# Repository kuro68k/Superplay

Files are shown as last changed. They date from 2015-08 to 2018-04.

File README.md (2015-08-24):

# SUPERPLAY

SUPERPLAY is an arcade joystick controller system. It consists of serveral parts.

The main SUPERPLAY PCB is fitted to the joystick and can either connect via USB or a custom KBUS. Both use the same USB cable. Configuration is via a Windows app called SPConfig.

SUPERPLAY supports up to 16 buttons, multiple autofire configurations with selectable fire rate, multiple options for switching modes and rotary joysticks (Seimitsu LS-30, used by SNK) for games like Midnight Resistance. Rotary joystick support is compatible with MAME, and configurable. SUPERPLAY also supports expansion boards via an expansion header, similar to Arduino sheilds.

####True zero lag

Many joystick controllers claim to be zero lag, but as FPS players know USB introduces some delay. USB HID devices are polled at 120Hz maximum, resulting in up to 8ms of lag (1/2 a frame at 60Hz). FPS players hack the Windows mouse driver to increase the poll rate, but it doesn't work for joysticks.

SUPERPLAY uses the excellent vJoy (vjoystick.sourceforge.net) and a custom USB interface to increase the polling rate to 1000Hz, reducing lag down to 1ms maximum. This gives true zero, arcade/console levels of input lag (i.e. none).

####Autofire

SUPERPLAY has a special autofire implementation that allows the player to set a precise frequency, and ensures that a button press is always registered when the button is first pushed. Simple autofire systems switch in a square wave, so the button press is sometimes not registered until the "on" part of the square wave comes around.

####KBUS

Aside from USB, SUPERPLAY can be connected to KBUS devices. Currently under development are a supergun with KBUS support, and a number of "recievers". Recievers connect to games consoles. The first is planned to support Playstation 1/2, Saturn and Dreamcast. Unfortunately due to licencing agreements Dreamcast support will not be published.

KBUS uses a simple 3.3V "RS232" compatible protocol, that can be easily implemented on low cost microcontrollers.

####Other stuff

A HID based USB bootloader will be provided for firmware and configuration updates. See my other projects for code.

The main SUPERPLAY PCB uses an XMEGA 128A3U microcontroller. This might be revised down to a 64KB in future. The project opens with Atmel Studio 6.2. Schematic and gerbers created in Eagle. V1.0 hardware has been built, V1.1 corrects a few issues.

SPConfig is built in Visual Studio 2013 Community Edition. I uses MahApps.Metro to create a "modern" UI.

Everything is licenced under GPL v3.

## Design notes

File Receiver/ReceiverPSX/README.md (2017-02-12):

# ReceiverPSX #

KBUS Receiever for:

- Sony Playstation 1
- Sony Playstation 2

Currently emulating a basic digital only pad.

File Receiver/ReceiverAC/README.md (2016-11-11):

# ReceiverACPS #

KBUS Receiever for:

- Atari/Commodore style 9 pin joystick ports  
  - Amiga (1-3 buttons)  
  - C64  
  - Atari 2600 / 7800 / ST etc.  
  - Many other 8/16 bit machines
- PC-Engine (Turbografx-16)
- Sega Master System
- Sega Megadrive (Genesis)

Any other simple switch/multiplex based system can also be supported, with the caveat that de-multiplexing is not as fast as real logic. Sega specify a 2uS delay from changing the multiplex selection to reading the outputs.

The generic XMEGA E5 receiver hardware is used. KBUS specifies 250mA @ 5V. Some systems, such as the Amiga, can't provide this from the joystick port so must get 5V from elsewhere (e.g. the floppy port). Of course not all KBUS devices need 250mA, so you may get away without it.

Lag is sub 1ms ("true zero", or at least 10x better than USB).

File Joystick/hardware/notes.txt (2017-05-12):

V1.0:	First issue

V1.1:	Minor fixes, firmware compatible.
		Fixed screw terminal hole sizes
		Moved test points further apart
		Added missing 1206 capacitor
		Revised logo

V1.2:	Connected PF4/UNUSED to LED
	Thickened lines in SUPERPLAY logos

V2 -> V1 mapping:

V2		V1
-------------
Up		Up
Down	Down
Left	Left
Right	Right

B1		B1
B2		B2
B3		B3
B4		B4
B5		B5
B6		B6
B7		B7
B8		B8
B9		Exp / AF low 1
B10		Exp / AF low 2
B11		Exp / AF low 3
B12		Exp / AF low 4
B13		AF low 6
B14		AF low 5
B15		Coin
B16		Start

A1		Unused
A2		Mode 4B
A3		Mode 4B AF
A4		Control
A5		AF high 1
A6		AF high 2
A7		AF high 3
A8		AF high 4

R1		R12
R2		R11
R3		R10
R4		R9
R5		R8
R6		R7
R7		R6
R8		R5
R9		R4
R10		R3
R11		R2
R12		R1

META	AF high 5
LED		AF high 6

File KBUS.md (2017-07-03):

# KBUS specification V0.1

KBUS is a high speed bus for video game controllers. It provides a low latency link and standard data format that is relatively easy to implement on common 8 bit microcontrollers and above. KBUS is a point-to-point bus, so there is always exactly one receiver and one device.

## Terminolgy

**Receiver**

The receiver is the bus master, issuing polling requests and other commands to devices. It's usually something like a PC or converter for a game console, which takes the player's input from devices.

**Device**

Devices respond to requests from the receiver by supplying data about user inputs. They are usually things like arcade joysticks, flight controls or converters for game console controllers. Devices are usually responsible for handling features like autofire, although receivers can optionally implement them as well.

## Electrical

KBUS uses RS232 signalling at 3.3V and 1M baud, 8 bits, no parity, 1 stop bit (8n1). This is easily implemented on most microcontrollers with a UART. Optionally, USB HID can be supported on the same cable with auto-detection.

Packets are separated by a gap of 2 or more characters.

The standard KBUS cable is a USB 2.0 cable. The type of connector on either end (A, B or C, micro, mini etc.) is not specified, but the standard full size A to B cable is cheap, readily available and fairly robust. D- is used for TX, and D+ for RX, from the receiver's point of view. Obviously, devices' TX/RX must be reversed.

`Receiver TX ---> USB D- ---> Device RX`
`Receiver RX <--- USB D+ <--- Device TX`

Power supplied to KBUS devices is 4.5-5.25V at 250mA. This allows for both standard USB 5V ±5% and for diode ORing of multiple supplies. Since signalling is at 3.3V it is expected that the supply voltage will be regulated down to that level anyway.

## Protocol

KBUS packets are 64 bytes long, for compatibility with USB HID. Each packet contains a command and up to 63 data bytes.

**KBUS over RS232 packet**

| Bytes | Description |
| :--- | :--- |
| 1 | Command code |
| 0-63 | Data |
| 2 | CCITT CRC-16 Checksum |

**KBUS over USB packet**

| Bytes | Description |
| :--- | :--- |
| 1 | Command code |
| 0-63 | Data |

USB handles the checksum as part of its own protocol, so there is no need to duplicate it. Commands are as follows:

| Command | Code | Description |
| :--- | :--- | :--- |
| ECHO | 0x50 | Echo data back, for testing/NOP |
| READ_STRING | 0x51 | Data byte indicates string ID<br>`0 - DEVICE_NAME`<br>`1 - MANUFACTURER`<br>`2 - SERIAL_NUMBER` |
| READ_VID_PID | 0x52 | Read 16 bit vendor/product IDs |
| | |
| START_REPORTING | 0x54 | Start sending continuous report packets at 1ms intervals |
| STOP_REPORTING | 0x55 | Stop sending continuous report packets |
| | |
| READ_REPORT | 0x5A | Request sending a report |
| | |
| ENTER_BOOTLOADER | 0x5B | Start bootloader (only on supported connections, e.g. USB) |

Strings are in Unicode UTF16-LE format, the same as USB. While Unicode has some severe limitations, USB compatibility makes it easy to implement dual protocol devices. To convert basic ISO 8859-1 / ASCII to UTF16-LE, just extend every byte to 16 bits and esure you have little-endian order. Strings do not need to be null terminated. Due to the packet length limit, the maximum string length is 31 characters.

Report packets must contain at least two data bytes, but can be up to 63 bytes. Currently only the following bytes are defined:

| Byte | Name | Description |
| :--- | :--- | :--- |
| 0 | UDLR_SSCC | (LSB) Up/down/left/right - start/select/coin/control (MSB) |
| 1 | BUTTONS1_8 | Buttons 1 - 8 (1 = LSB) |
| 2 | BUTTONS9_16 | Buttons 9 - 16 |
| 3 | ROT_MODE | Bits 0-3 - Rotary position 0-11<br>Bits 4-5 - Button mode<br>Bits 6-7 - Unused |

Receivers can ignore inputs they don't need / understand.

## Polling and activation

Receivers often need to poll KBUS ports to see if a device is attached. Polling also gives devices an opportunity to calibrate internal oscillators/UARTs and signal to the receiver that they are ready.

Polling starts by the receiver sending 64 0xFF bytes. 0xFF produces just one low pulse per byte that is 1uS wide. The receiver can measure the width of this bit for oscillator calibration / auto-bauding. When ready, the device should respond with 0x0F, which again provides useful timing data and an opportunity to test the receiver's UART. The device should keep transmitting until the receiver stops sending 0xFF bytes for at least 10ms. If the receiver does not see a response for 10ms, it can send another burst of 64 0xFF bytes and repeat the cycle indefinitely.

Once both receiver and device are quiet for at least 10ms, the receiver should send an ECHO command to test the link, followed optionally by polling IDs and strings, before starting to request reports.

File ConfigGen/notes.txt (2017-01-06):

Autofire affects _b inputs, not logical buttons. This allows physical buttons with and without AF for each logical button.

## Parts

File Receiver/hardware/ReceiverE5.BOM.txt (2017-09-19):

Title:      KBUS Receiver
Date:       12/07/2017 16:29:38
Source:     ReceiverE5.sch
Revsision:  2.1

No.  Reference             Value          Footprint                 Precision

[ Capacitors, 6 values, X7R/X5R, 16V unless otherwise stated ]
-----------------------------------------------------------------------------
2    C1, C2                22p            0603                      
1    C3                    4.7u           0603                      
6    C4, C5, C10, C11      100n           0603                      
     C12, C13
1    C6                    680p           0603                      
2    C7, C9                10u            0603                      
1    C8                    10u            0805                      

[ Diodes, 2 values ]
-----------------------------------------------------------------------------
1    D1                    LED            0603                      
1    D2                    MBR0520LT1G    SOD-123                   

[ Connectors, 5 values ]
-----------------------------------------------------------------------------
1    J1                    KBUS           Type A, TH, FCI 87520     
1    J2                    AVR-PDI-6A     Pin_Header_Straight_2x03  
1    J3                    CONN_01X08     no part                   
2    J4, J5                CONN_01X06     no part                   
2    J6, J7                CONN_01X04     no part                   

[ Inductors, 1 value ]
-----------------------------------------------------------------------------
1    L1                    6.8u           SRN4012TA                 

[ Resistors, 5 values, 1% unless otherwise stated ]
-----------------------------------------------------------------------------
3    R1, R2, R3            680            0603                      
1    R4                    47k            0603                      
1    R5                    15k            0603                      
1    R6                    2k2            0603                      
2    R7, R8                33             0603                      

[ SW, 1 value ]
-----------------------------------------------------------------------------
1    SW1                   SW_SPST        SW_SPST_EVQP7C            

[ Integrated Circuits, 5 values ]
-----------------------------------------------------------------------------
1    U1                    ATXMEGA32E5-A  TQFP-32                   
1    U2                    LM2731         SOT-23                    
2    U3, U4                SN74LV07A      SSOP-14                   
1    U5                    TPS78233       SOT-23                    
2    U6, U7                74LVC2T45      SOT-765-1                 

[ Crystals, 1 value ]
-----------------------------------------------------------------------------
1    Y1                    Crystal        QC6CB/7A/ABM7 crystals

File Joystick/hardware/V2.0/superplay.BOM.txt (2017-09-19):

Title:      SUPERPLAY joystick controller
Date:       12/07/2017 11:46:48
Source:     superplay.sch
Revsision:  2.0
Company:    KEIO

No.  Reference             Value            Footprint                       Precision

[ Capacitors, 5 values, X7R/X5R, 16V unless otherwise stated ]
-------------------------------------------------------------------------------------
1    C1                    1u               0603                            
1    C2                    100u             1206                            
1    C3                    10u              0603                            
6    C4, C5, C6, C7, C8    100n             0603                            
     C9
2    C10, C11              18p              0603                            

[ Diodes, 1 value ]
-------------------------------------------------------------------------------------
1    D1                    LED              0603                            

[ Connectors, 3 values ]
-------------------------------------------------------------------------------------
1    J1                    AVR-PDI-6A       3x2_1.27mm_SMD_header           
1    J2                    CONN_02X04       ...r_Straight_2x04_Pitch2.54mm  
1    J3                    USB_B            USB_Micro-B_Molex_47346-0001    

2    PA1, PA2              CONN_01X05       B5B-ZR-SM4-TF                   
4    PB1, PB2, PB3, PB4    CONN_01X05       B5B-ZR-SM4-TF                   
1    PJ1                   CONN_01X05       B5B-ZR-SM4-TF                   
1    PL1                   CONN_01X02       B2B-ZR-SM4-TF                   
1    PM1                   CONN_01X02       B2B-ZR-SM4-TF                   
3    PR1, PR2, PR3         CONN_01X05       B5B-ZR-SM4-TF                   

[ Resistors, 1 value, 1% unless otherwise stated ]
-------------------------------------------------------------------------------------
1    R1                    680R             0603                            

[ Integrated Circuits, 3 values ]
-------------------------------------------------------------------------------------
1    U1                    MCP1700T-3002E   SOT-23                          
1    U2                    ATXMEGA128A3U-A  TQFP-64_14x14mm_Pitch0.8mm      
1    U3                    TPD4S009DBV      SOT-23                          

[ Crystals, 1 value ]
-------------------------------------------------------------------------------------
1    Y1                    16MHz            QC6CB/7A/ABM7 crystals

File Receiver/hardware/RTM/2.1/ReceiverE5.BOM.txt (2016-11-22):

Title	KBUS Receiver
Date	22/11/2016 09:59:38
Source	ReceiverE5.sch
Revsision	2.0

Capacitors	6	X7R/X5R, 16V unless otherwise stated
	C1, C2	22p	0603	
	C6	680p	0603	
	C4, C5, C10, C11, C12, C13	100n	0603	
	C7, C9	10u	0603	
	C8	10u	0805	
	C3	4.7u	0603	

Diodes	2
	D2	MBR0520LT1G	SOD-123	
	D1	LED	0603	

Connectors	5
	J1	KBUS	Type A, TH, FCI 87520	
	J2	AVR-PDI-6A		

Inductors	1
	L1	6.8u		

Resistors	5	1% unless otherwise stated
	 R1, R2,R3	680	0603	
	R7, R8	33	0603	
	R6	2k2	0603	
	R5	15k	0603	
	R4	47k	0603	

Integrated Circuits	5
	U2	LM2731	SOT-23	
	U5	TPS78233	SOT-23	
	U1	ATXMEGA32E5-A	TQFP-32	
	U3, U4	SN74LV07A	SSOP-14	
	U6, U7	74LVC2T45	SOT-765-1	

Crystals	1
	Y1	Crystal	QC6CB/7A/ABM7 crystals

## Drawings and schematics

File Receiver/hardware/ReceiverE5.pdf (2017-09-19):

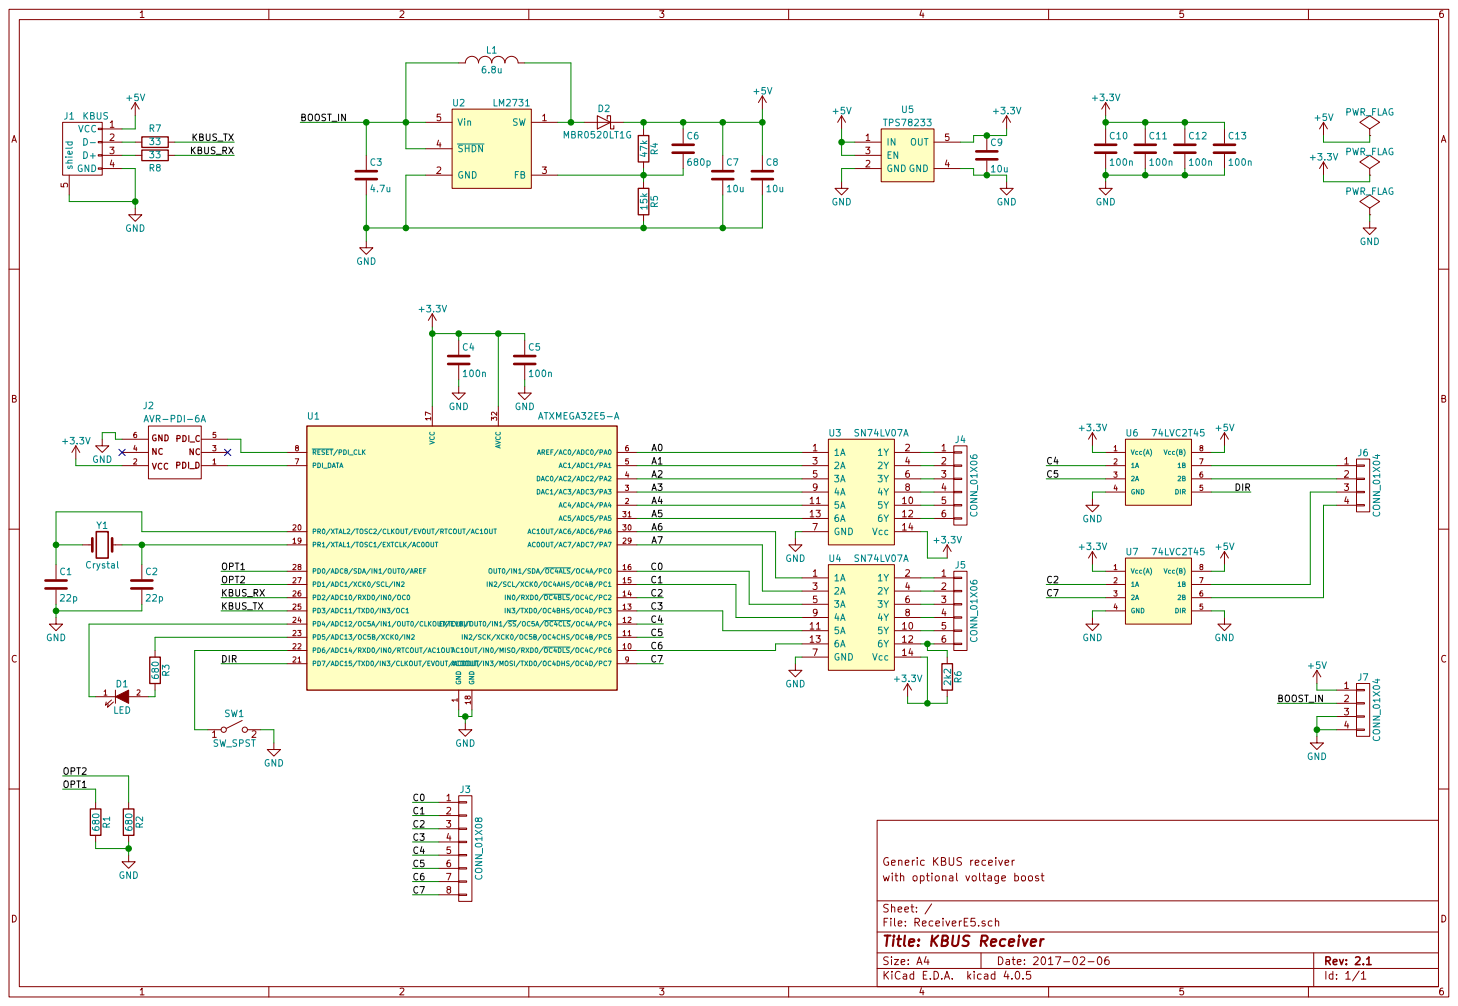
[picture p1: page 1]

1 AC4/ADC4/PA4 2 DAC1/AC3/ADC3/PA3 3 DAC0/AC2/ADC2/PA2 4 AC1/ADC1/PA1 5 AREF/AC0/ADC0/PA0 6 PDI_DATA 7 RESET/PDI_CLK 8 AC0OUT/IN3/MOSI/TXD0/OC4DHS/OC4D/PC7 9 AC1OUT/IN0/MISO/RXD0/OC4DLS/OC4C/PC6 10 PR0/XTAL2/TOSC2/CLKOUT/EVOUT/RTCOUT/AC1OUT 20 AC1OUT/AC6/ADC6/PA6 30

Id: 1/1 Title: KBUS Receiver File: ReceiverE5.sch Sheet: / with optional voltage boost Generic KBUS receiver

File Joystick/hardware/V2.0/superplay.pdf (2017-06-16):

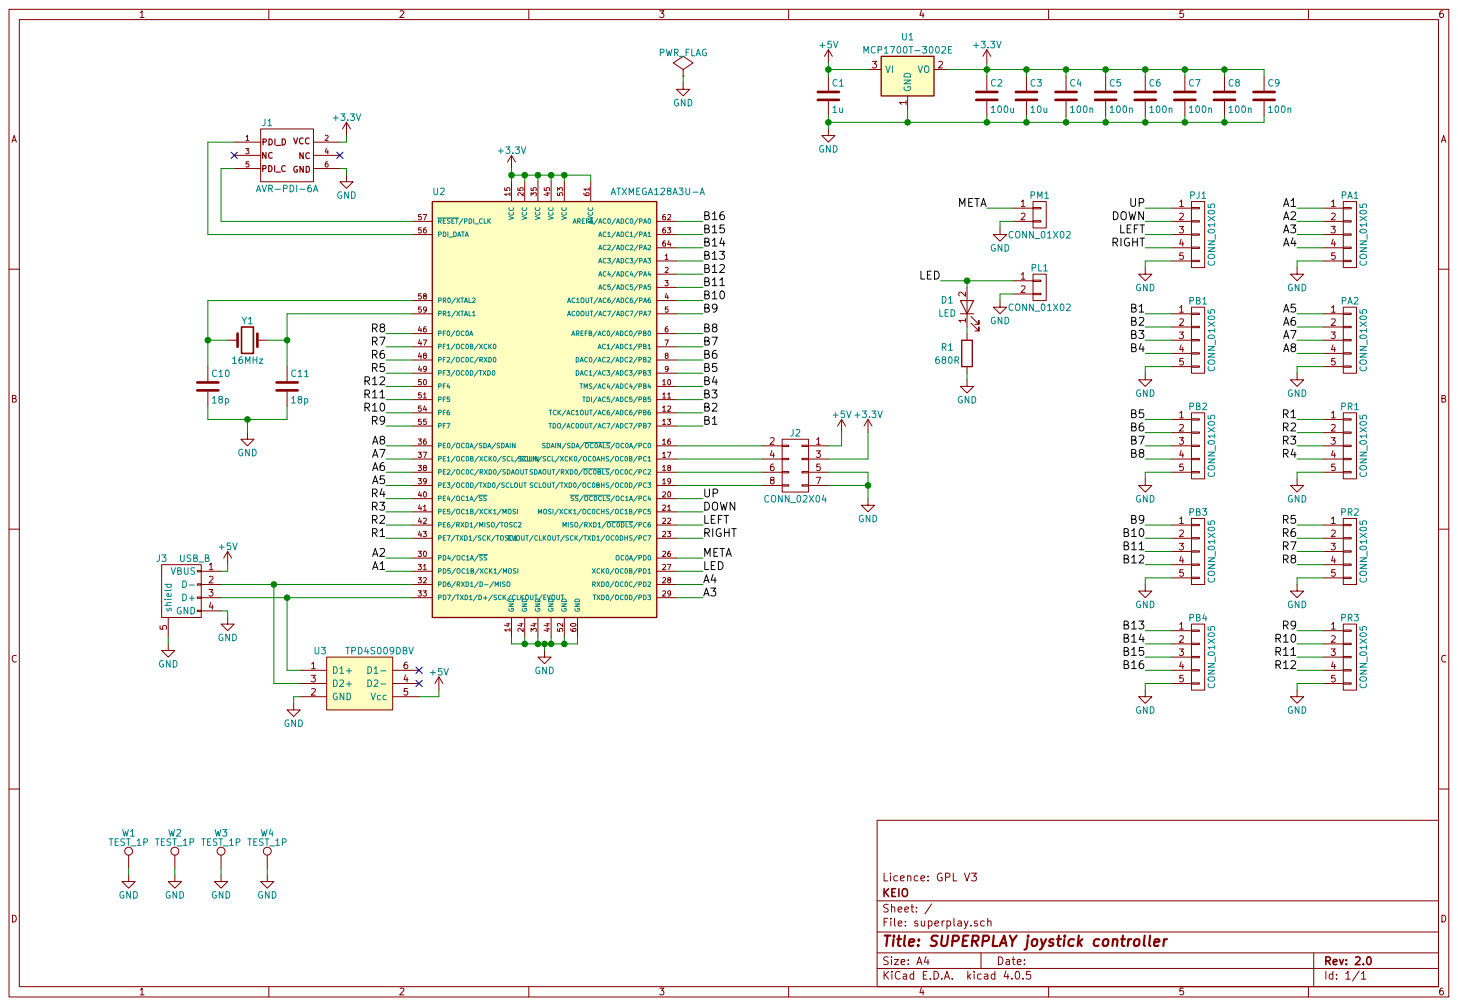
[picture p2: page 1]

2 PL1 CONN_01X02 GND GND GND META

Licence: GPL V3
File: superplay.sch Sheet: / KEIO

Id: 1/1 Title: SUPERPLAY joystick controller

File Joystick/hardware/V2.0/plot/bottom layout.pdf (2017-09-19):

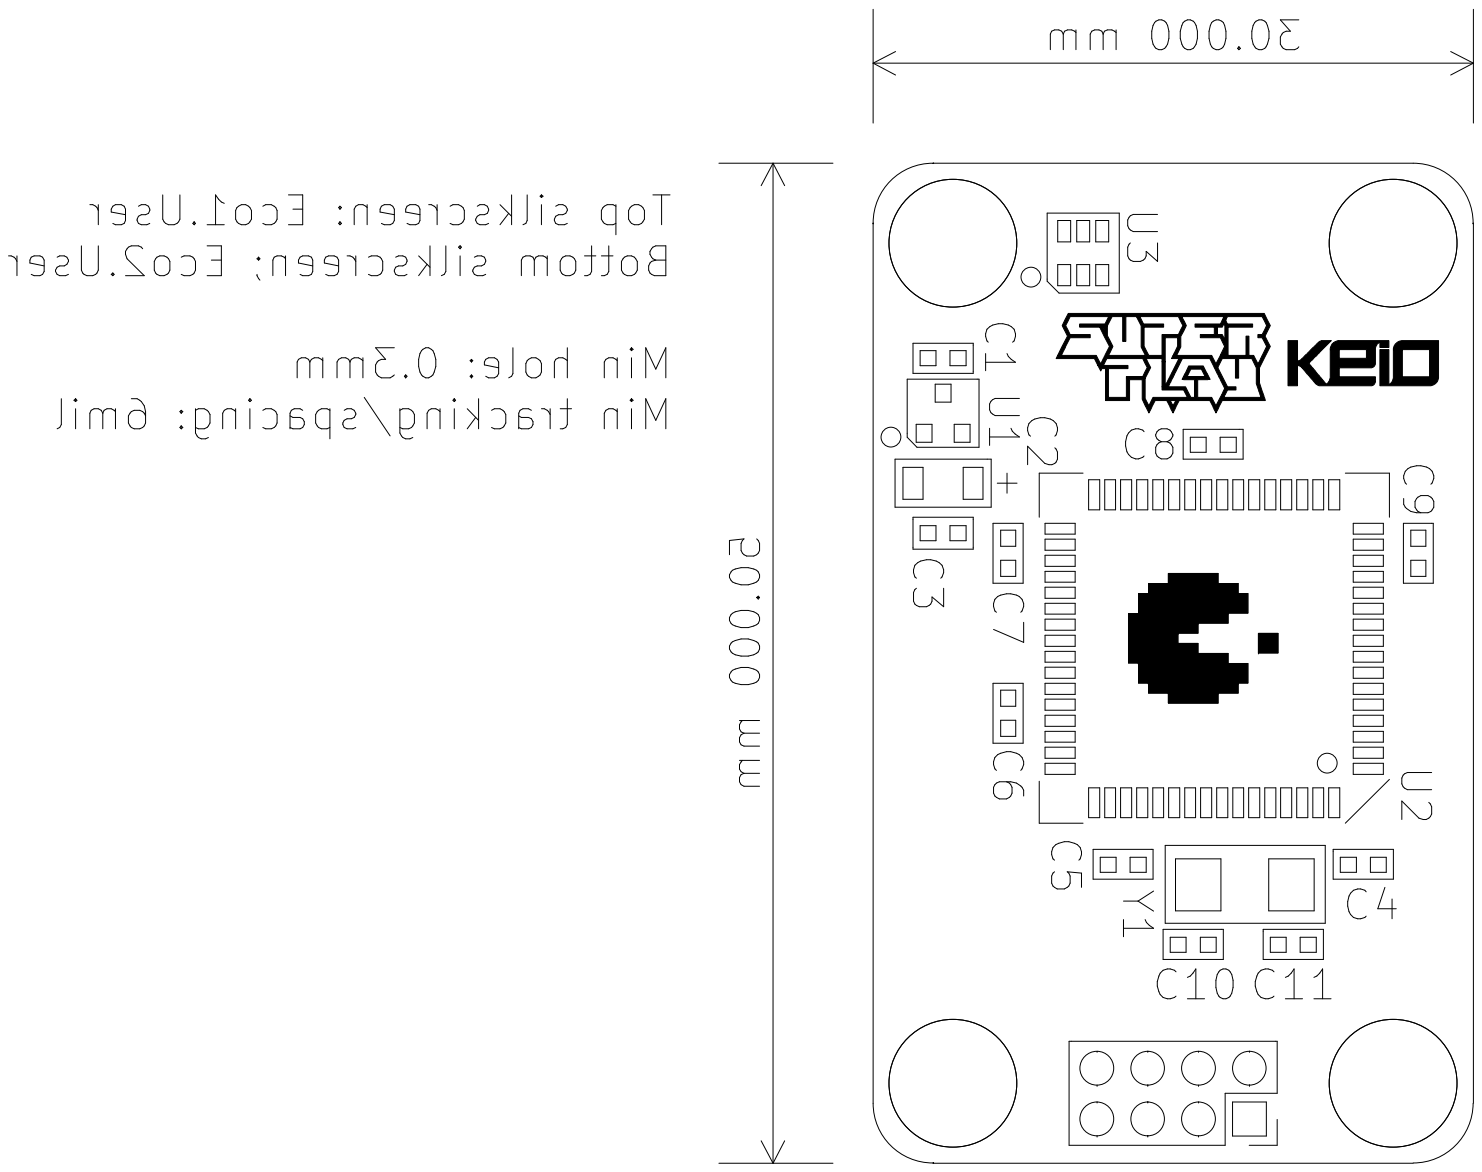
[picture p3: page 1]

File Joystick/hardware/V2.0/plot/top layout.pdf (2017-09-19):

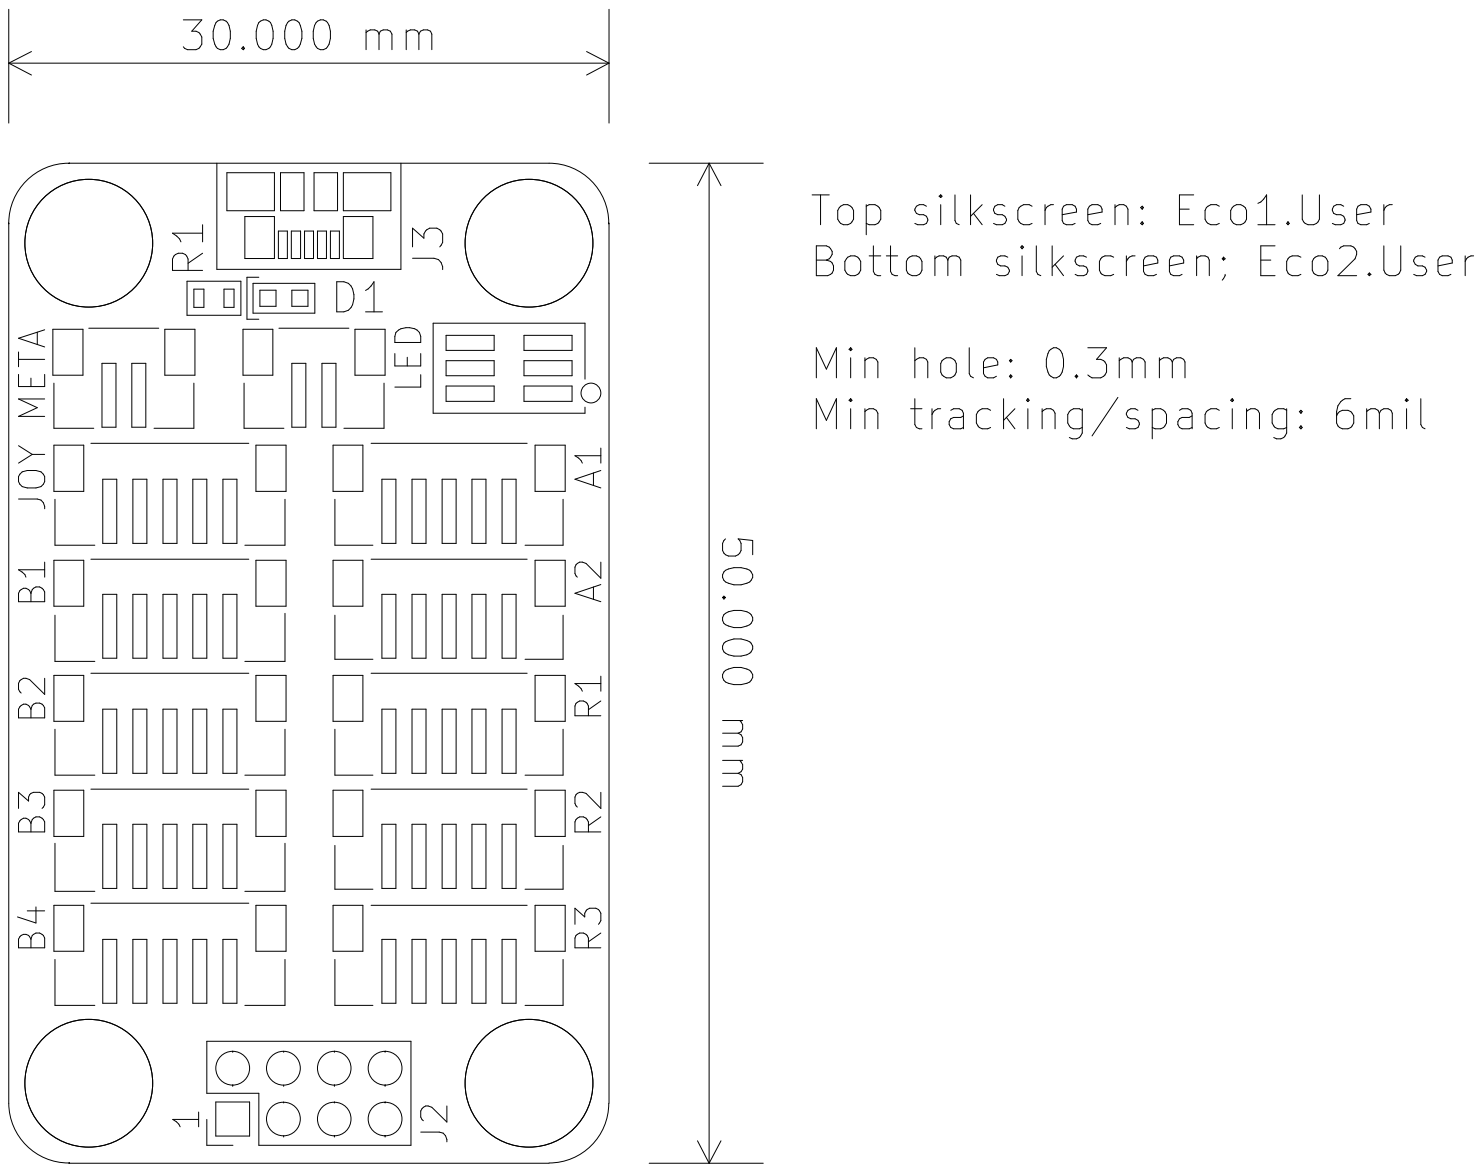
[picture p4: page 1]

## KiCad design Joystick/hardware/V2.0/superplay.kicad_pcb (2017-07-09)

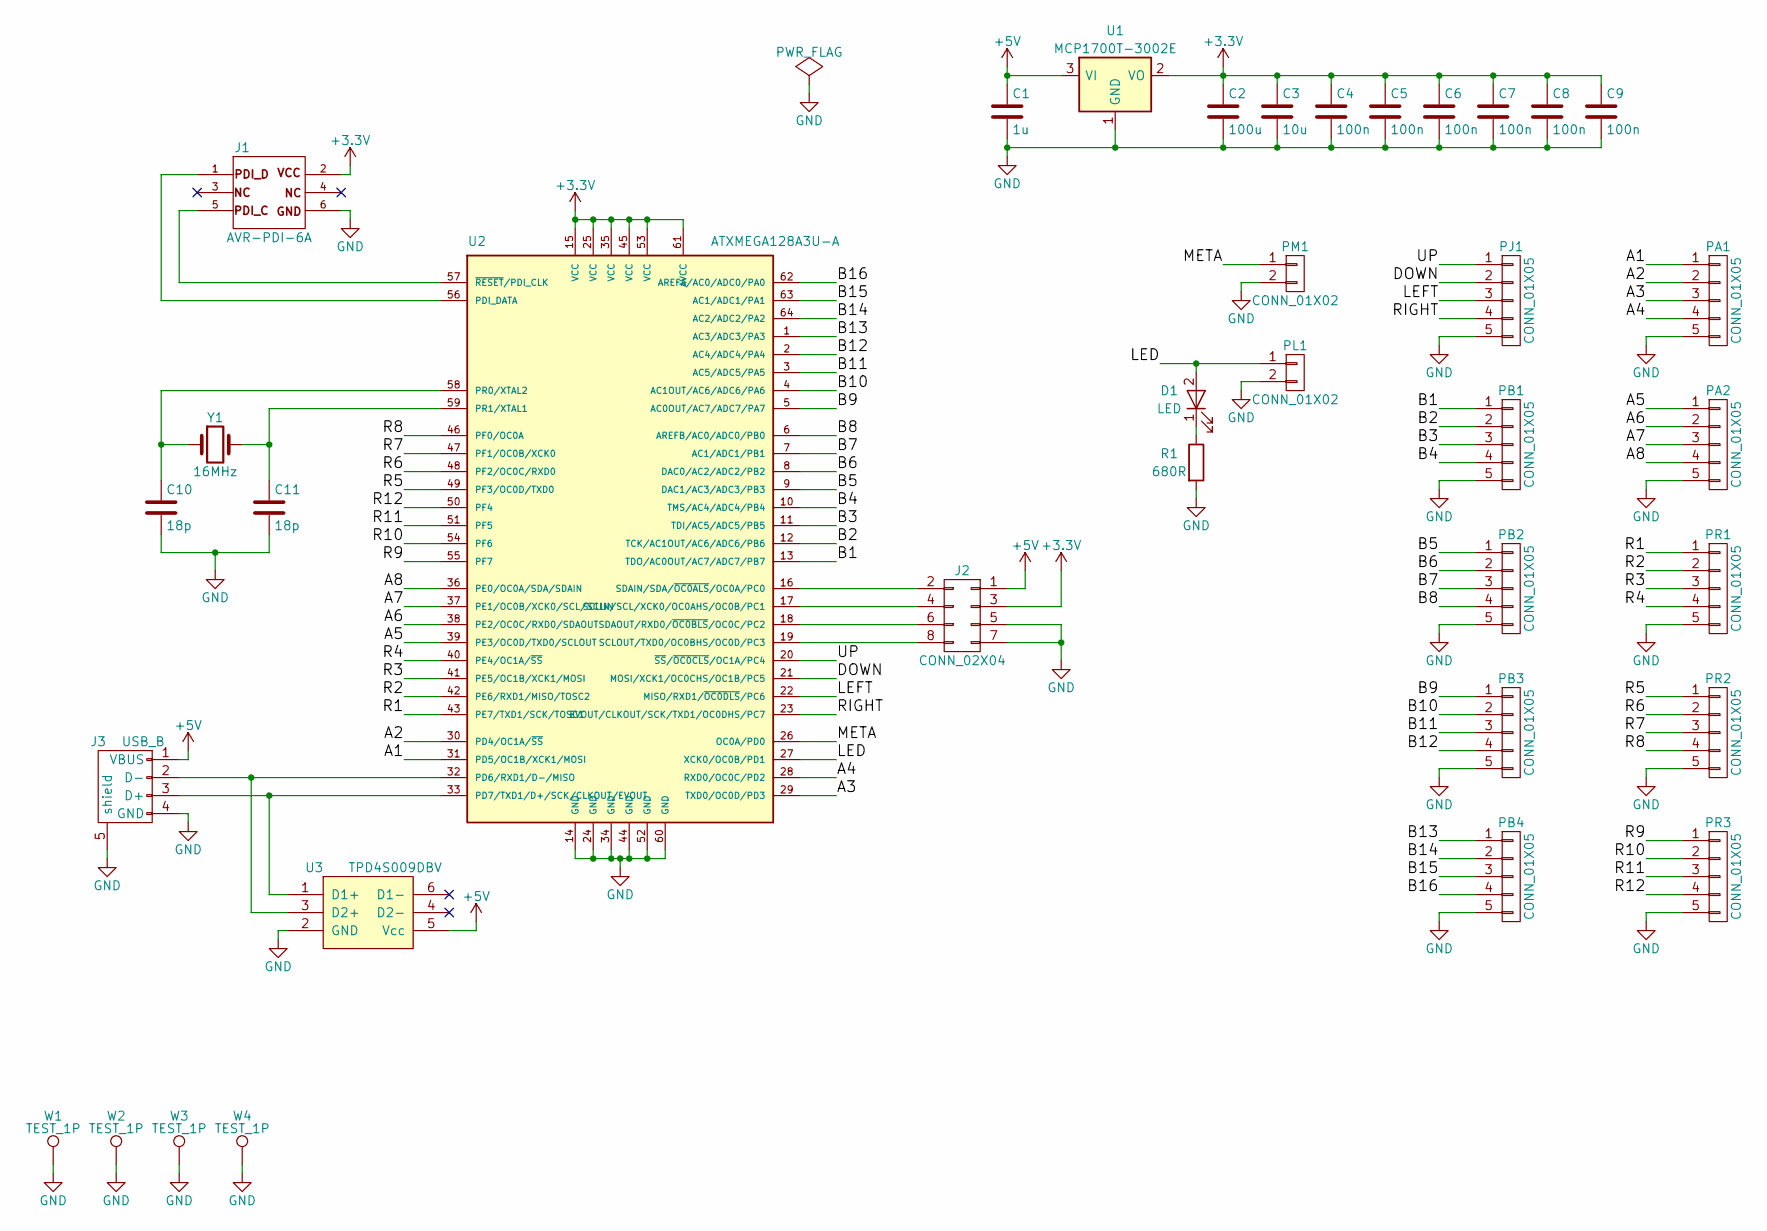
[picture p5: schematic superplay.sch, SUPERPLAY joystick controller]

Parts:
C1: 1u; C_0603
C2: 100u; C_1206
C3: 10u; C_0603
C4, C5, C6, C7, C8, C9: 100n; C_0603
C10, C11: 18p; C_0603
D1: LED; LED_0603
J1: AVR-PDI-6A; 3x2_1.27mm_SMD_header
J2: CONN_02X04; Pin_Header_Straight_2x04_Pitch2.54mm
J3: USB_B; USB_Micro-B_Molex_47346-0001
PA1, PA2: CONN_01X05; B5B-ZR-SM4-TF
PB1, PB2, PB3, PB4: CONN_01X05; B5B-ZR-SM4-TF
PJ1: CONN_01X05; B5B-ZR-SM4-TF
PL1: CONN_01X02; B2B-ZR-SM4-TF
PM1: CONN_01X02; B2B-ZR-SM4-TF
PR1, PR2, PR3: CONN_01X05; B5B-ZR-SM4-TF
R1: 680R; R_0603
U1: MCP1700T-3002E; SOT-23
U2: ATXMEGA128A3U-A; TQFP-64_14x14mm_Pitch0.8mm
U3: TPD4S009DBV; SOT-23-6
W1, W2, W3, W4: TEST_1P; MountingHole_3.2mm_M3_Pad
Y1: 16MHz; SMD_Crystal_Multi_QC6CB_7A_ABM7

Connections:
+3V3: C2.1, C3.1, C4.1, C5.1, C6.1, C7.1, C8.1, C9.1, J1.2, J2.3, U1.2 (VO), U2.15 (VCC), U2.25 (VCC), U2.35 (VCC), U2.45 (VCC), U2.53 (VCC), U2.61 (AVCC)
+5V: C1.1, J2.1, J3.1 (VBUS), U1.3 (VI), U3.5 (Vcc)
/A1: PA1.1, U2.31 (PD5/OC1B/XCK1/MOSI)
/A2: PA1.2, U2.30 (PD4/OC1A/~SS~)
/A3: PA1.3, U2.29 (TXD0/OC0D/PD3)
/A4: PA1.4, U2.28 (RXD0/OC0C/PD2)
/A5: PA2.1, U2.39 (PE3/OC0D/TXD0/SCLOUT)
/A6: PA2.2, U2.38 (PE2/OC0C/RXD0/SDAOUT)
/A7: PA2.3, U2.37 (PE1/OC0B/XCK0/SCL/SCLIN)
/A8: PA2.4, U2.36 (PE0/OC0A/SDA/SDAIN)
/B1: PB1.1, U2.13 (TDO/AC0OUT/AC7/ADC7/PB7)
/B2: PB1.2, U2.12 (TCK/AC1OUT/AC6/ADC6/PB6)
/B3: PB1.3, U2.11 (TDI/AC5/ADC5/PB5)
/B4: PB1.4, U2.10 (TMS/AC4/ADC4/PB4)
/B5: PB2.1, U2.9 (DAC1/AC3/ADC3/PB3)
/B6: PB2.2, U2.8 (DAC0/AC2/ADC2/PB2)
/B7: PB2.3, U2.7 (AC1/ADC1/PB1)
/B8: PB2.4, U2.6 (AREFB/AC0/ADC0/PB0)
/B9: PB3.1, U2.5 (AC0OUT/AC7/ADC7/PA7)
/B10: PB3.2, U2.4 (AC1OUT/AC6/ADC6/PA6)
/B11: PB3.3, U2.3 (AC5/ADC5/PA5)
/B12: PB3.4, U2.2 (AC4/ADC4/PA4)
/B13: PB4.1, U2.1 (AC3/ADC3/PA3)
/B14: PB4.2, U2.64 (AC2/ADC2/PA2)
/B15: PB4.3, U2.63 (AC1/ADC1/PA1)
/B16: PB4.4, U2.62 (AREFA/AC0/ADC0/PA0)
/DOWN: PJ1.2, U2.21 (MOSI/XCK1/OC0CHS/OC1B/PC5)
/LED: D1.2 (A), PL1.1, U2.27 (XCK0/OC0B/PD1)
/LEFT: PJ1.3, U2.22 (MISO/RXD1/~OC0DLS~/PC6)
/META: PM1.1, U2.26 (OC0A/PD0)
/R1: PR1.1, U2.43 (PE7/TXD1/SCK/TOSC1)
/R2: PR1.2, U2.42 (PE6/RXD1/MISO/TOSC2)
/R3: PR1.3, U2.41 (PE5/OC1B/XCK1/MOSI)
/R4: PR1.4, U2.40 (PE4/OC1A/~SS~)
/R5: PR2.1, U2.49 (PF3/OC0D/TXD0)
/R6: PR2.2, U2.48 (PF2/OC0C/RXD0)
/R7: PR2.3, U2.47 (PF1/OC0B/XCK0)
/R8: PR2.4, U2.46 (PF0/OC0A)
/R9: PR3.1, U2.55 (PF7)
/R10: PR3.2, U2.54 (PF6)
/R11: PR3.3, U2.51 (PF5)
/R12: PR3.4, U2.50 (PF4)
/RIGHT: PJ1.4, U2.23 (EVOUT/CLKOUT/SCK/TXD1/OC0DHS/PC7)
/UP: PJ1.1, U2.20 (~SS~/~OC0CLS~/OC1A/PC4)
GND: C1.2, C2.2, C3.2, C4.2, C5.2, C6.2, C7.2, C8.2, C9.2, C10.2, C11.2, J1.6, J2.5, J2.7, J3.4 (GND), J3.5 (shield), PA1.5, PA2.5, PB1.5, PB2.5, PB3.5, PB4.5, PJ1.5, PL1.2, PM1.2, PR1.5, PR2.5, PR3.5, R1.2, U1.1 (GND), U2.14 (GND), U2.24 (GND), U2.34 (GND), U2.44 (GND), U2.52 (GND), U2.60 (GND), U3.2 (GND), W1.1, W2.1, W3.1, W4.1
unnamed: C10.1, U2.58 (PR0/XTAL2), Y1.1
unnamed: C11.1, U2.59 (PR1/XTAL1), Y1.2
unnamed: D1.1 (K), R1.1
unnamed: J1.1, U2.56 (PDI_DATA)
unnamed: J1.5, U2.57 (~RESET~/PDI_CLK)
unnamed: J2.2, U2.16 (SDAIN/SDA/~OC0ALS~/OC0A/PC0)
unnamed: J2.4, U2.17 (SCLIN/SCL/XCK0/OC0AHS/OC0B/PC1)
unnamed: J2.6, U2.18 (SDAOUT/RXD0/~OC0BLS~/OC0C/PC2)
unnamed: J2.8, U2.19 (SCLOUT/TXD0/OC0BHS/OC0D/PC3)
unnamed: J3.2 (D-), U2.32 (PD6/RXD1/D-/MISO), U3.3 (D2+)
unnamed: J3.3 (D+), U2.33 (PD7/TXD1/D+/SCK/CLKOUT/EVOUT), U3.1 (D1+)

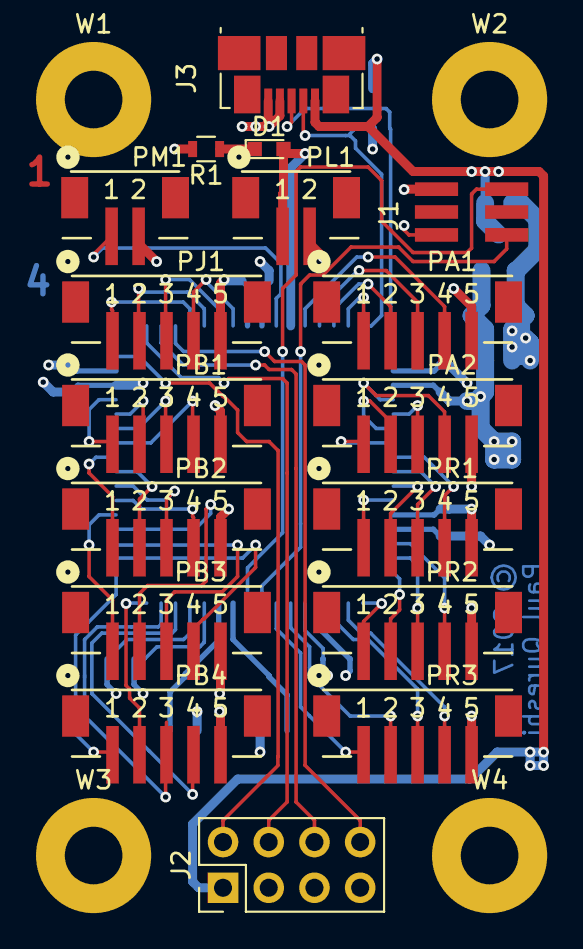
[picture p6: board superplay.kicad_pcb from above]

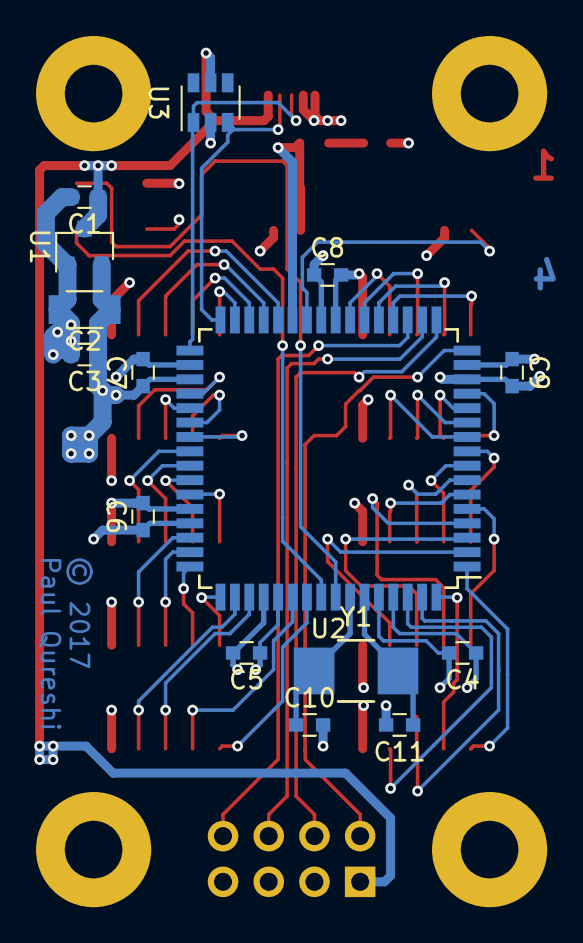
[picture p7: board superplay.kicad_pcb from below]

Board: 4 copper layers, 36 parts (15 on the bottom side), 56 nets.

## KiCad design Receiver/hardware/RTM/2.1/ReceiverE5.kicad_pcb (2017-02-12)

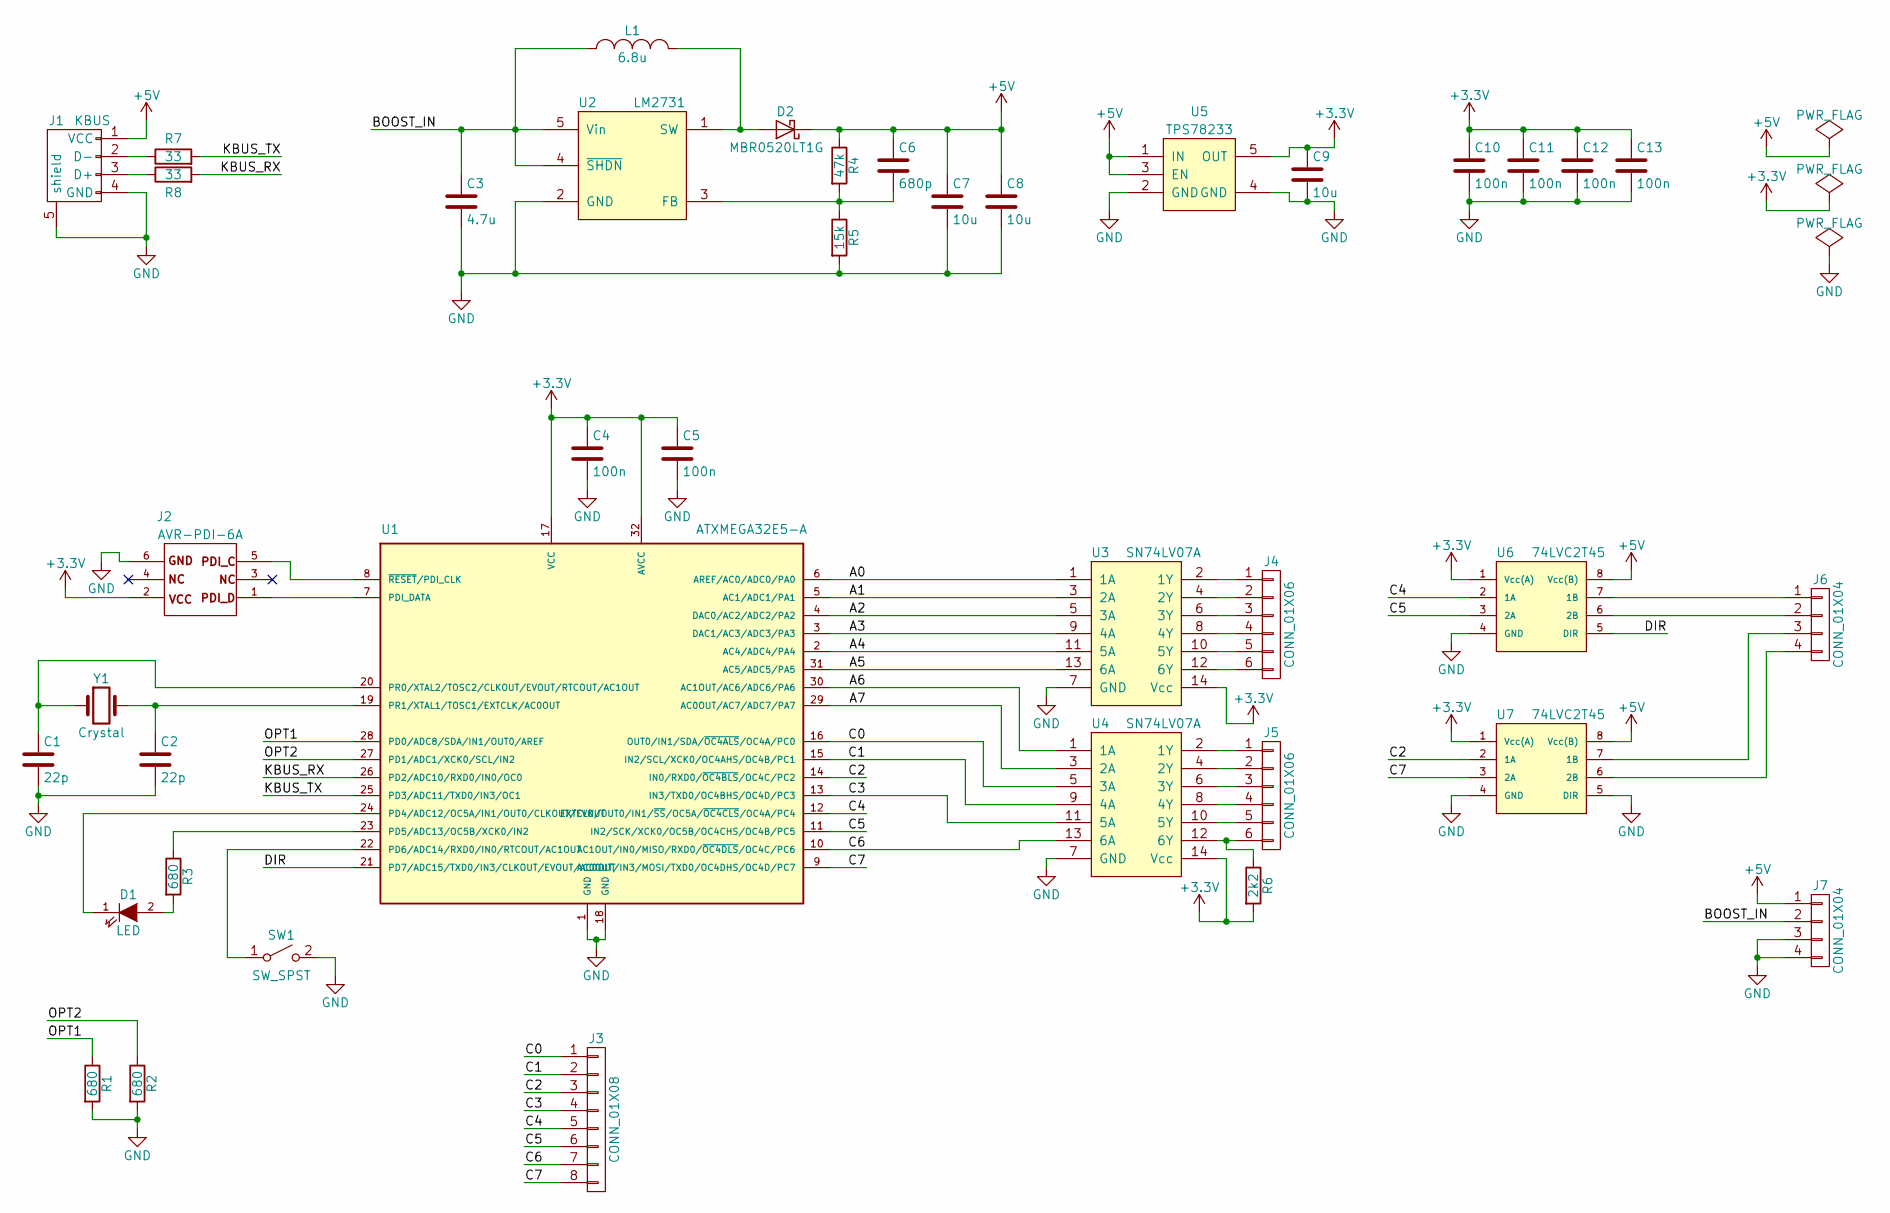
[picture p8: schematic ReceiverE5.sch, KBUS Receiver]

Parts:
C1, C2: 22p; C_0603
C3: 4.7u; C_0603
C4, C5, C10, C11, C12, C13: 100n; C_0603
C6: 680p; C_0603
C7, C9: 10u; C_0603
C8: 10u; C_0805
D1: LED; R_0603
D2: MBR0520LT1G; SOD-123
J1: KBUS; USB_A_multicomp
J2: AVR-PDI-6A; Pin_Header_Straight_2x03
J3: CONN_01X08; Pin_Header_Straight_1x08
J4, J5: CONN_01X06; Pin_Header_Straight_1x06
J6, J7: CONN_01X04; Pin_Header_Straight_1x04
L1: 6.8u; SRN4012TA
R1, R2, R3: 680; R_0603
R4: 47k; R_0603
R5: 15k; R_0603
R6: 2k2; R_0603
R7, R8: 33; R_0603
SW1: SW_SPST; SW_SPST_EVQP7C
U1: ATXMEGA32E5-A; TQFP-32_7x7mm_Pitch0.8mm
U2: LM2731; SOT-23-5
U3, U4: SN74LV07A; SSOP-14
U5: TPS78233; SOT-23-5
U6, U7: 74LVC2T45; VSSOP8_SOT765-1
Y1: Crystal; SMD_Crystal_Multi_QC6CB_7A_ABM7

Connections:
+3V3: C4.1, C5.1, C9.1, C10.1, C11.1, C12.1, C13.1, J2.2, R6.2, U1.17 (VCC), U1.32 (AVCC), U3.14 (Vcc), U4.14 (Vcc), U5.5 (OUT), U6.1 (Vcc(A)), U7.1 (Vcc(A))
+5V: C6.1, C7.1, C8.1, D2.1 (K), J1.1 (VCC), J7.1, R4.1, U5.1 (IN), U5.3 (EN), U6.8 (Vcc(B)), U7.8 (Vcc(B))
/A0: U1.6 (AREF/AC0/ADC0/PA0), U3.1 (1A)
/A1: U1.5 (AC1/ADC1/PA1), U3.3 (2A)
/A2: U1.4 (DAC0/AC2/ADC2/PA2), U3.5 (3A)
/A3: U1.3 (DAC1/AC3/ADC3/PA3), U3.9 (4A)
/A4: U1.2 (AC4/ADC4/PA4), U3.11 (5A)
/A5: U1.31 (AC5/ADC5/PA5), U3.13 (6A)
/A6: U1.30 (AC1OUT/AC6/ADC6/PA6), U4.1 (1A)
/A7: U1.29 (AC0OUT/AC7/ADC7/PA7), U4.3 (2A)
/BOOST_IN: C3.1, J7.2, L1.1, U2.4 (~SHDN), U2.5 (Vin)
/C0: J3.1, U1.16 (OUT0/IN1/SDA/~OC4ALS~/OC4A/PC0), U4.5 (3A)
/C1: J3.2, U1.15 (IN2/SCL/XCK0/OC4AHS/OC4B/PC1), U4.9 (4A)
/C2: J3.3, U1.14 (IN0/RXD0/~OC4BLS~/OC4C/PC2), U7.2 (1A)
/C3: J3.4, U1.13 (IN3/TXD0/OC4BHS/OC4D/PC3), U4.11 (5A)
/C4: J3.5, U1.12 (EXTCLK/OUT0/IN1/~SS~/OC5A/~OC4CLS~/OC4A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), U6.2 (1A)
/C5: J3.6, U1.11 (IN2/SCK/XCK0/OC5B/OC4CHS/OC4B/PC5), U6.3 (2A)
/C6: J3.7, U1.10 (AC1OUT/IN0/MISO/RXD0/~OC4DLS~/OC4C/PC6), U4.13 (6A)
/C7: J3.8, U1.9 (AC0OUT/IN3/MOSI/TXD0/OC4DHS/OC4D/PC7), U7.3 (2A)
/DIR: U1.21 (PD7/ADC15/TXD0/IN3/CLKOUT/EVOUT/AC0OUT), U6.5 (DIR)
/KBUS_RX: R8.2, U1.26 (PD2/ADC10/RXD0/IN0/OC0)
/KBUS_TX: R7.2, U1.25 (PD3/ADC11/TXD0/IN3/OC1)
/OPT1: R1.1, U1.28 (PD0/ADC8/SDA/IN1/OUT0/AREF)
/OPT2: R2.1, U1.27 (PD1/ADC1/XCK0/SCL/IN2)
GND: C1.2, C2.2, C3.2, C4.2, C5.2, C7.2, C8.2, C9.2, C10.2, C11.2, C12.2, C13.2, J1.4 (GND), J1.5 (shield), J2.6, J7.3, J7.4, R1.2, R2.2, R5.2, SW1.2 (B), U1.1 (GND), U1.18 (GND), U2.2 (GND), U3.7 (GND), U4.7 (GND), U5.2 (GND), U5.4 (GND), U6.4 (GND), U7.4 (GND), U7.5 (DIR)
unnamed: C1.1, U1.20 (PR0/XTAL2/TOSC2/CLKOUT/EVOUT/RTCOUT/AC1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), Y1.1
unnamed: C2.1, U1.19 (PR1/XTAL1/TOSC1/EXTCLK/AC0OUT), Y1.2
unnamed: C6.2, R4.2, R5.1, U2.3 (FB)
unnamed: D1.1 (K), U1.24 (PD4/ADC12/OC5A/IN1/OUT0/CLKOUT/EVOUT)
unnamed: D1.2 (A), R3.2
unnamed: D2.2 (A), L1.2, U2.1 (SW)
unnamed: J1.2 (D-), R7.1
unnamed: J1.3 (D+), R8.1
unnamed: J2.1, U1.7 (PDI_DATA)
unnamed: J2.5, U1.8 (~RESET~/PDI_CLK)
unnamed: J4.1, U3.2 (1Y)
unnamed: J4.2, U3.4 (2Y)
unnamed: J4.3, U3.6 (3Y)
unnamed: J4.4, U3.8 (4Y)
unnamed: J4.5, U3.10 (5Y)
unnamed: J4.6, U3.12 (6Y)
unnamed: J5.1, U4.2 (1Y)
unnamed: J5.2, U4.4 (2Y)
unnamed: J5.3, U4.6 (3Y)
unnamed: J5.4, U4.8 (4Y)
unnamed: J5.5, U4.10 (5Y)
unnamed: J5.6, R6.1, U4.12 (6Y)
unnamed: J6.1, U6.7 (1B)
unnamed: J6.2, U6.6 (2B)
unnamed: J6.3, U7.7 (1B)
unnamed: J6.4, U7.6 (2B)
unnamed: R3.1, U1.23 (PD5/ADC13/OC5B/XCK0/IN2)
unnamed: SW1.1 (A), U1.22 (PD6/ADC14/RXD0/IN0/RTCOUT/AC1OUT)

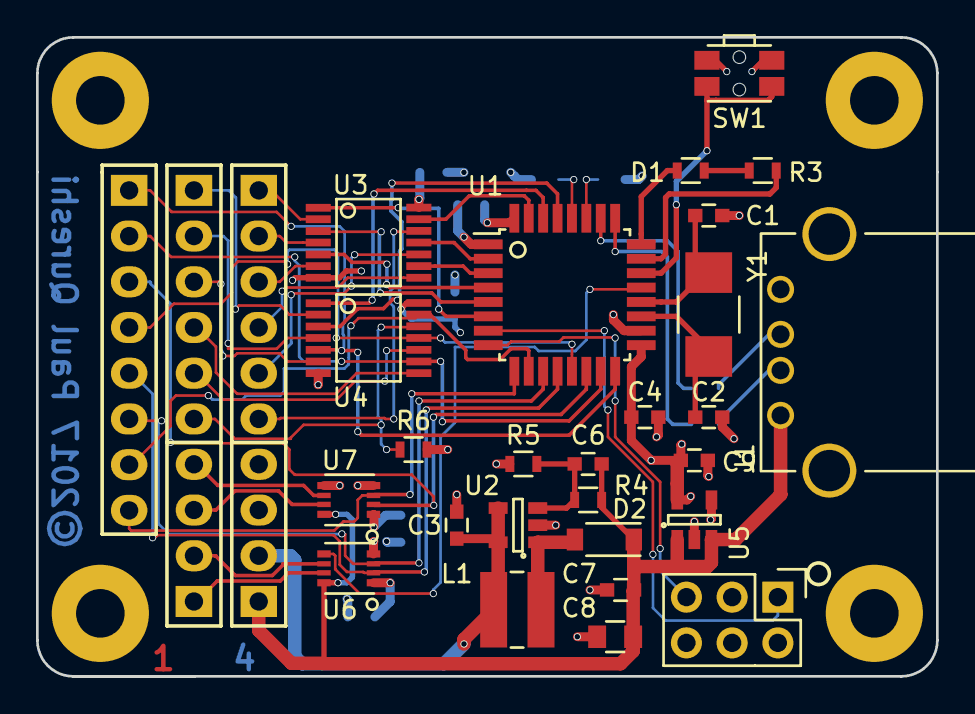
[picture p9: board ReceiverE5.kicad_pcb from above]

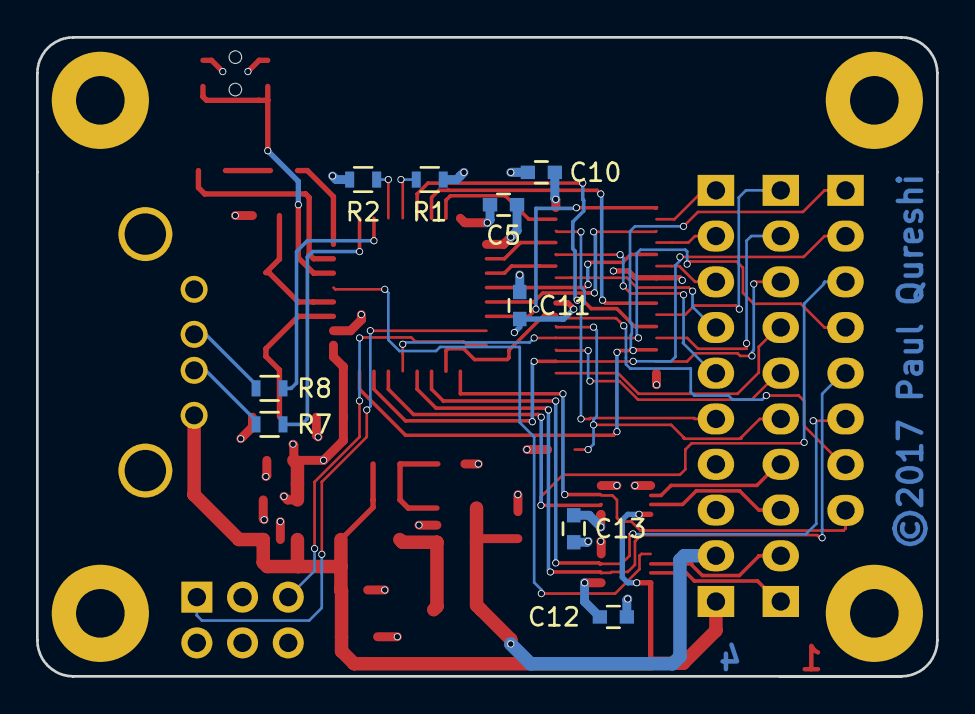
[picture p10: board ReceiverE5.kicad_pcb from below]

Board: 4 copper layers, 50.0 x 35.5 mm, 42 parts (9 on the bottom side), 53 nets.

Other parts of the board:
KEIO: LOGO; logo2_16x5mm
SUPERPLAY: LOGO; superplay1.1t_29.8x4.8_flipped

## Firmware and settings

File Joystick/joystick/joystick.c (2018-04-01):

/*
 * joystick.c
 *
 */


#include <avr/io.h>
#include <util/delay.h>
#include <asf.h>

#include "global.h"
#include "hw_misc.h"
#include "config.h"
#include "hid.h"
#include "report.h"
#include "autofire.h"
#include "serial_num.h"
#include "usart.h"
#include "aux_buttons.h"
#include "keys.h"


#define VERSION_MAJOR	1
#define VERSION_MINOR	0

typedef struct {
	char		magic_string[8];
	uint8_t		version_major;
	uint8_t		version_minor;
	uint8_t		mcu_signature[3];
	uint32_t	flash_size_b;
	uint16_t	page_size_b;
	uint32_t	eeprom_size_b;
	uint16_t	eeprom_page_size_b;
} FW_INFO_t;

// data embedded in firmware image so that the bootloader program can read it
volatile const __flash FW_INFO_t firmware_info =	{	{ 0x59, 0x61, 0x6d, 0x61, 0x4e, 0x65, 0x6b, 0x6f },		// "YamaNeko" magic identifier
														VERSION_MAJOR,
														VERSION_MINOR,
														{ SIGNATURE_0, SIGNATURE_1, SIGNATURE_2 },
														APP_SECTION_SIZE,
														APP_SECTION_PAGE_SIZE,
														EEPROM_SIZE,
														EEPROM_PAGE_SIZE
													};

int main(void)
{
	firmware_info.magic_string[0];	// prevent firmware_info being optimized away

//	PORTF.DIRSET = PIN0_bm | PIN1_bm | PIN2_bm;
//	PORTF.OUTCLR = PIN0_bm | PIN1_bm | PIN2_bm;

	sysclk_init();
	CFG_init();
	HW_init();
	AF_init();
	HID_init();
	USB_init_build_usb_serial_number();
	USART_init();
	AB_init();

//	PORTCFG.CLKEVOUT = PORTCFG_CLKOUTSEL_CLK1X_gc | PORTCFG_CLKOUT_PC7_gc;
//	PORTC.DIRSET = PIN7_bm;

	PMIC.CTRL = PMIC_LOLVLEN_bm | PMIC_MEDLVLEN_bm | PMIC_HILVLEN_bm;
	sei();
/*
	bool usart_mode = false;
	for(;;)
	{
		if (HID_check_for_bus())
			break;
		if ((usart_mode = USART_check_for_bus()))
			break;
	}
*/
	//PORTD.DIRSET = PIN1_bm;

	udc_start();
	udc_attach();

	for(;;)
	{
		WDR();

		RPT_refresh_input_matrix();
		AF_apply();
		RPT_refresh_leds();
		//KEY_read();

		//if (cfg->aux_mode == AUX_MODE_BUTTONS)
		//	AB_send_report();

//PORTD.OUTSET = PIN1_bm;
		//if (!usart_mode)
			HID_send_report();
		//else
		//	USART_run();
//PORTD.OUTCLR = PIN1_bm;
	}
}

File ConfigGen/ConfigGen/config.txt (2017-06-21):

; example config

; general settings
begin SETTINGS
	af_high_hz = 15
	af_high_duty_pc = 50
	af_low_hz = 5
	af_low_duty_pc = 50

	led_display_mapping = 1				; 0 = off, 1 = position, 2 = binary
	led_display_timeout_ms = 2000

	meta_af_toggle = 0b111				; button bitmap
	meta_af_select_with_stick = 1
	meta_mapping_select_with_stick = 1
end

; output pins
begin OUTPUTS
	_a9 = led1
	_a10 = led2
	_a11 = led3
end

; PC Engine translation
begin PCE
	up = up
	down = down
	left = left
	right = right
	button1 = button2		; PC Engine buttons are numbered right-to-left
	button2 = button1
	select = button3
	run = start
end

; 1 default button mapping
begin MAPPING
	up		= _up
	down	= _down
	left	= _left
	right	= _right

	button1 = _b1
	button2 = _b2
	button3 = _b3
	start = _start

	meta = _start

	led1 = af_high1
	led2 = af_high2
	led3 = af_high3
end

; 2 reversed button mapping
begin MAPPING
	up		= _up
	down	= _down
	left	= _left
	right	= _right

	button1 = _b3
	button2 = _b2
	button3 = _b1
	start = _start

	meta = _start

	led1 = af_high1
	led2 = af_high2
	led3 = af_high3
end

; 3 one button mode
begin MAPPING
	up		= _up
	down	= _down
	left	= _left
	right	= _right

	button1 = _b1
	button1 = _b2
	button1 = _b3
	button1 = _b4

	meta = _start

	led1 = af_high1
	led2 = af_high2
	led3 = af_high3
end

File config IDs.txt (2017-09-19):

0	not used
1	Joystick settings
2	Joystick outputs

4	Mapping 1
...
16	Mapping 12

17	PC Engine mapping
18	PC Engine 6 button mode mapping
19	Atari mapping
20	Sega 3 button

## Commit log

2015-08-25 Autofire updates
    Added AF toggle mode
    Fixes for AF modes and settings
    [report.c]
2015-10-14 Fixed physical -> logical mapping
    [report.c]
2015-11-01 Fixed default mapping
    Logical map == 0 means end of list
    [joystick.c]
2015-11-01 Fixed and tested bootloader
    Also fixed EEPROM writing and fuses
    [hw_misc.c]
2016-04-04 DMA RX for USART
2016-04-15 Fixed a couple of compiler warnings
    [joystick.c]
2016-04-15 Started on AUX button output
2016-04-18 Aux buttons complete, to be tested
2016-11-11 Receiver E5 hardware added
    [ReceiverE5.kicad_pcb, ReceiverE5.sch]
2016-11-14 Finished adding footprints
    [ReceiverE5.sch]
2016-11-14 Added optional MISO pull-up
    [ReceiverE5.sch]
2016-11-14 Fixed a few minor schematic errors
    [ReceiverE5.sch]
2016-11-14 Changed PDI header to 2.54mm pitch TH
    [ReceiverE5.sch]
2016-11-14 Started work on PCB layout
    [ReceiverE5.kicad_pcb]
2016-11-14 Set up design limits
    [ReceiverE5.kicad_pcb]
2016-11-14 Routing try 1
    [ReceiverE5.kicad_pcb]
2016-11-14 Routing try 2
    [ReceiverE5.kicad_pcb]
2016-11-14 Added mounting holes
    [ReceiverE5.kicad_pcb]
2016-11-15 50x30mm layout
    [ReceiverE5.kicad_pcb]
2016-11-15 Rounded corners off
    [ReceiverE5.kicad_pcb]
2016-11-15 Boost/linear reg
    [ReceiverE5.kicad_pcb]
2016-11-15 2 layer power routing try 1
    [ReceiverE5.kicad_pcb]
2016-11-15 Added missing series termination resistors for KBUS
    [ReceiverE5.kicad_pcb, ReceiverE5.sch]
2016-11-15 Finished signal routing
    [ReceiverE5.kicad_pcb, _saved_ReceiverE5.sch]
2016-11-15 2 layer power routing part 2
    [ReceiverE5.kicad_pcb]
2016-11-15 4 layer all routed
    No unrouted nets
    [ReceiverE5.kicad_pcb]
2016-11-15 Unconnected net fixed, DRC passes
    [ReceiverE5.kicad_pcb]
2016-11-16 Changed all holes to min 3mm, need to fix DRC errors
    [ReceiverE5.kicad_pcb]
2016-11-16 Passed DRC again
    [ReceiverE5.kicad_pcb]
2016-11-16 USB connector was on wrong side of the board
    [ReceiverE5.kicad_pcb]
2016-11-16 Silk + mounting holes changed to M2.5
    [ReceiverE5.kicad_pcb]
2016-11-16 Silkscreen tidied up
    [ReceiverE5.kicad_pcb]
2016-11-16 Metadata + PDF schematic
    [ReceiverE5.kicad_pcb, ReceiverE5.sch, _saved_ReceiverE5.sch]
2016-11-16 SVG output + settings
    [ReceiverE5.kicad_pcb]
2016-11-17 Laser cut case design
2016-11-18 Added some extra fields for BOM generation with kibom
    [ReceiverE5.sch]
2016-11-18 Rounded case design
2016-11-22 Added BOM + notes
    [ReceiverE5.sch]
2017-01-06 Started work on new ConfigGen
    [config.txt, config2.txt]
2017-01-12 Generates binary blobs
    [config.txt, config2.txt]
2017-01-19 Switched to Keio.Utils..dll for text utils and Intel Hex functions
2017-01-27 Corrected bootloader entry logic, added button
2017-01-27 Added optional LED
2017-01-27 Config ID registry
    [config IDs.txt]
2017-01-29 Fixed flexible length array/sizeof() issue
    [joystick.c, report.c]
2017-01-29 HID working, AF broken
    [hw_misc.c, joystick.c, report.c]
2017-01-29 Fixed AF timer calculation
2017-02-06 Widened board, added button
    [ReceiverE5.kicad_pcb, ReceiverE5.sch]
2017-02-06 Fixed position of USB
    [ReceiverE5.kicad_pcb]
2017-02-08 Top silk
    [ReceiverE5.kicad_pcb, ReceiverE5.sch]
2017-02-08 Version per host
    [ReceiverE5.kicad_pcb]
2017-02-08 Bottom silkscreen
    [ReceiverE5.kicad_pcb]
2017-02-12 Receiver 2.1 release
    [ReceiverE5-B.Cu.gbl, ReceiverE5-B.Mask.gbs, ReceiverE5-B.Paste.gbp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]
2017-05-10 moved receiver directories
    [ReceiverE5-B.Cu.gbl, ReceiverE5-B.Mask.gbs, ReceiverE5-B.Paste.gbp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]
2017-05-10 Cleaned up receiver hardware directory
    [ReceiverE5-B.Cu.gbl, ReceiverE5-B.Mask.gbs, ReceiverE5-B.Paste.gbp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]
2017-05-10 Manufactured releases
    [ReceiverE5-B.Cu.gbl, ReceiverE5-B.Mask.gbs, ReceiverE5-B.Paste.gbp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]
2017-05-10 Composite -> HID only USB device
    [joystick_controller.GBL, joystick_controller.GBO, joystick_controller.GBP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]
2017-05-11 Fixed button entry mechanism
2017-05-11 Removed unwanted copy
    [joystick_controller.GBL, joystick_controller.GBO, joystick_controller.GBP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]
2017-05-11 Moved expansion port to add I2C
2017-05-11 V2.0 schematic
    [superplay.kicad_pcb, superplay.sch]
2017-05-12 Assigned footprints
    [_saved_superplay.sch]
2017-05-12 Finished foorprint assignments
    [_saved_superplay.sch, superplay.sch]
2017-05-12 Fixed ERCs
    [superplay.sch]
2017-05-14 Started PCB layout
    [superplay.kicad_pcb, superplay.sch]
2017-05-16 30x50mm board
    [superplay.kicad_pcb, superplay.sch]
2017-05-16 Routing attempt
    [superplay.kicad_pcb]
2017-05-17 Rewired to make PCB layout easier
    [superplay.kicad_pcb, superplay.sch]
2017-05-17 Routing looks successful
    [superplay.kicad_pcb, superplay.sch]
2017-05-17 Routing power
    [superplay.kicad_pcb]
2017-05-18 Routing finished, passes DRC
    [superplay.kicad_pcb]
2017-05-19 Layer numbers
    [superplay.kicad_pcb]
2017-05-20 Added SUPERPLAY logo
    [superplay.kicad_pcb]
2017-05-20 Keio + graphic
    [superplay.kicad_pcb]
2017-05-20 KEIO logo was backwards
    [superplay.kicad_pcb]
2017-06-21 Test config file
    [config.txt]
2017-07-09 Min hole size fixed, drill file for Seeed OK
    [superplay-B.Cu.gbl, superplay-B.Mask.gbs, superplay-Eco1.User.gto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]
2017-07-11 Config loading over KBUS
    [config IDs.txt]
2017-07-11 Faster button mapping
2017-07-12 Schematic PDF and BOM refresh
2017-07-12 Added BOM
2017-07-12 Updated BOM
2017-09-19 Upgraded to Kicad 4.0.7
    [superplay.sch]
2017-10-01 Inverted I/O for more efficient mapping
    [hw_misc.c]

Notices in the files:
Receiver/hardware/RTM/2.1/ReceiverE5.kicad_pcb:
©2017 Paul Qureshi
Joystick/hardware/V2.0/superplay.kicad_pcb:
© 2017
